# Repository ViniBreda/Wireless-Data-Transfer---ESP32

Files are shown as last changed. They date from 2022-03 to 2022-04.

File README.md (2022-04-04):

# Wireless Data Transfer Between two ESP32 - DOIT Devkit

* File upload via bluetooth available BUT VERY SLOW;
* Send a 500KB file from one ESP32 to another, atleast 100m apart from eachother;
* The PCB of the transmission board was designed considering up to eight I²C devices connected to it to works as a sensor DataLogger;
* The receiver PCB is just a normal DOIT Devkit 1 remake to learn how to use KiCad;
* This is just a concept, not all funcionalities will be developed/tested as the main goal is to send a file over a Wireless Conection.

## TODO : 
 * [x] Enable/Disable BT file transfer
 * [x] Write WiFi AP file transfer
 * [x] RTC sync to log time of [HTTP] GET request
 * [x] RTC sync to execute [HTTP] GET request every 5 minutes
 * [x] Test WiFi Long Range and Normal WiFi
 * [x] Successful test on cellphone hosted WiFi Hotspot - Download file via http://ESP-IP-ADDRESS/download
 * [x] Successful file transfer between two ESP32 boards

## Description:

ESP32 was selected over Arduino boards because:
* it has an internal flash memory that can store more than 500kB of data;
* it has both bluetooth and Wi-Fi onboard;
* it has Wi-Fi Long Range, which is great for file transfers of up to 1Km;
* it's low power mode has very low power consumption, which is great for battery powered projects;
* great market availability, atleast in Brazil;
* higher clock rate;
* internal RTC module;
* cheap price;
* 15 analog pins on DOIT ESP32 DevKit 1 that are great for reading data from sound and light sensors, for example;
* Possibility to code using Arduino syntax, which I'm more familiar to.

Other boards were not considered, such as MSP430 from Texas Instruments or STM32 from STMicroelectronics, because of the difficulties to acquire these boards in Brazil with as many functionalities as ESP32 for as low of a price as a DOIT ESP32 Devkit1.

Both transmissor and receiver schematics can be found below:

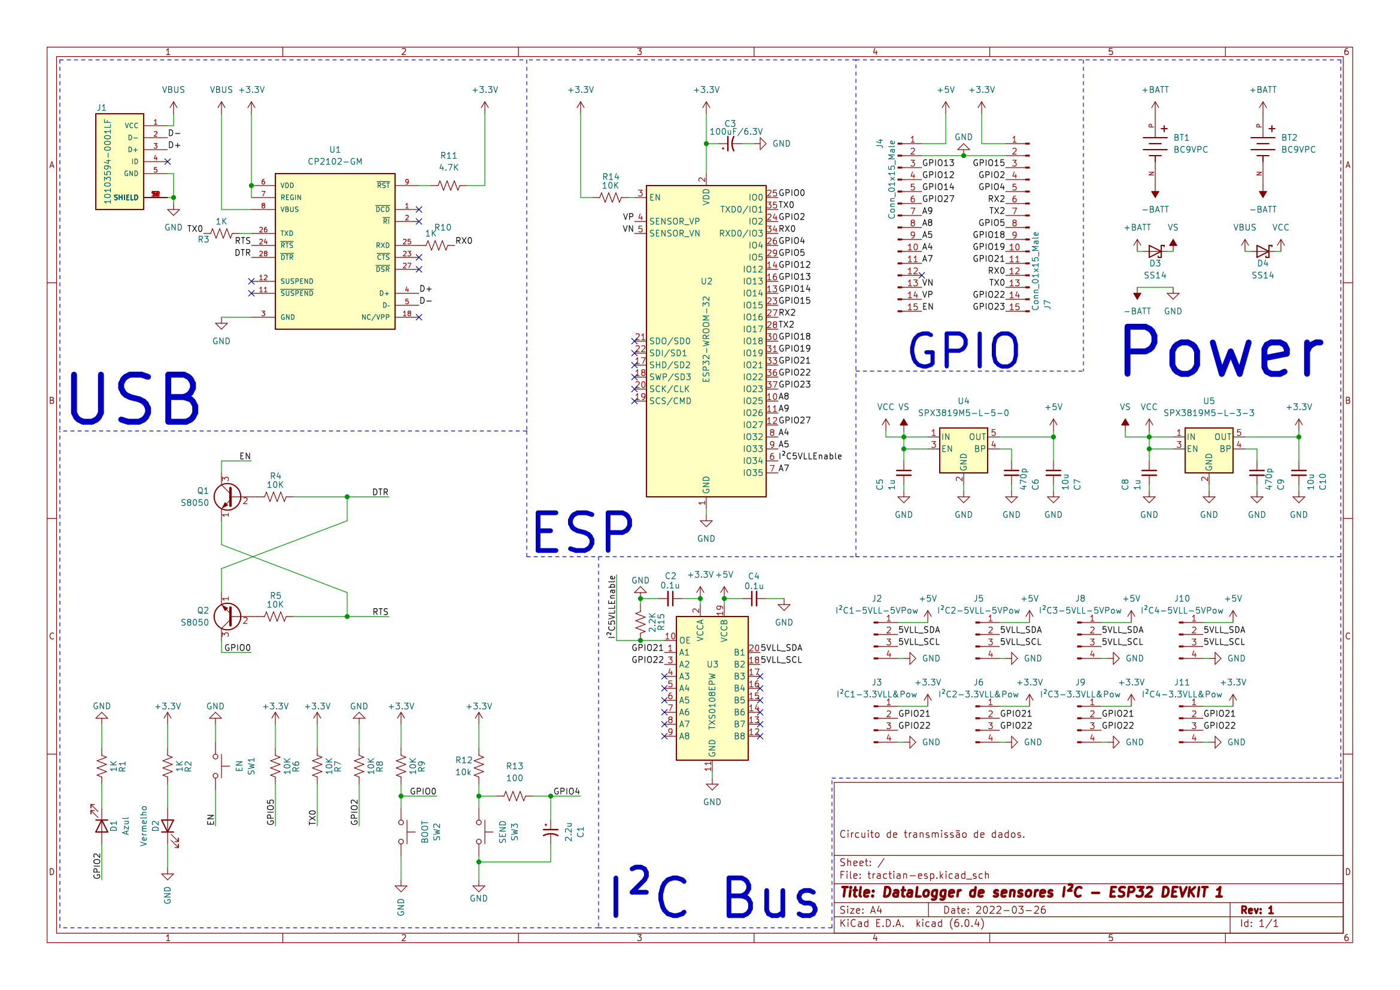
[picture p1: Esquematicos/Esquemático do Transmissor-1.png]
Transmissor


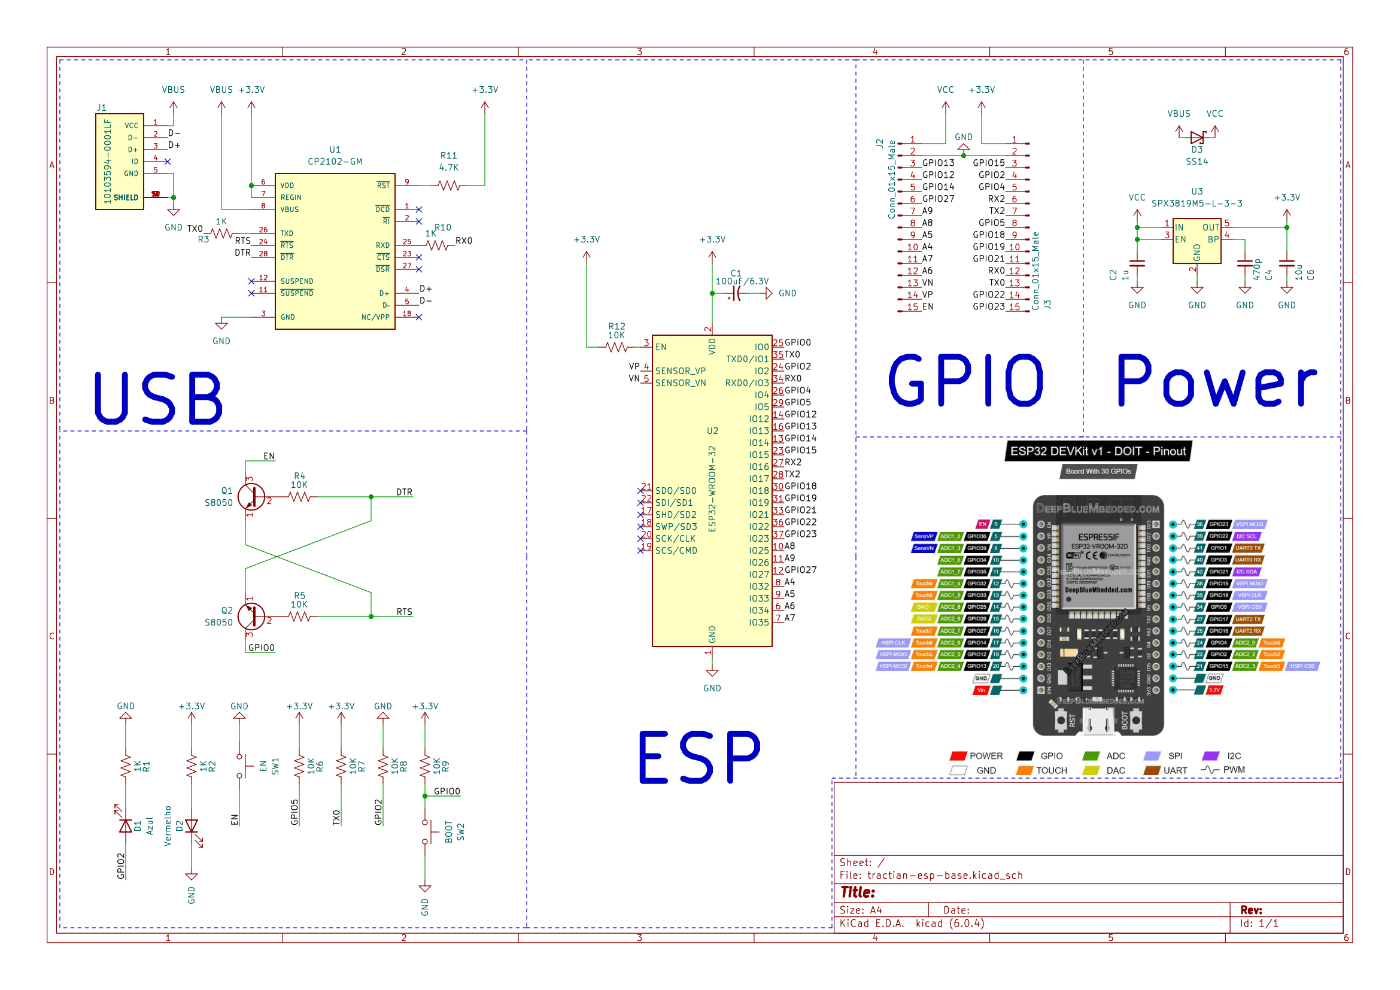
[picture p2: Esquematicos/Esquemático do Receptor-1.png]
Receiver


As there was no need for external components, the schematics would be fairly simple, so I decided to add some details on the transmissor, designing it to be a DataLogger that should read data from it's I²C. This required a logic level converter for I²C devices that need 5V for power and output 5V logic level signals, as ESP32's high level is 3.3V maximum. Also, I used as an example the schematics for the original DOIT ESP32 Devkit 1, changing some of the voltage regulators for ones with lower dropout voltage.

As I was using KiCAD for the first time, designing both the transmissors and receivers was a great challenge and I'm happy with the final result. Common 9V batteries can be used for thisn project and will power the device for many hours.

The transmissor design sacrifices one of the GPIOs with less functionality to have it as I²C enable for the logic level converter. I²C will work normally with this pin on LOW, but I²C for 5V power 5V logic level signal devices this pin has to be put on high while data is being sent and received. It's a great measure to ensure a lower power draw.

The board design for both transmissor and receiver can be found below:

<p align="left">
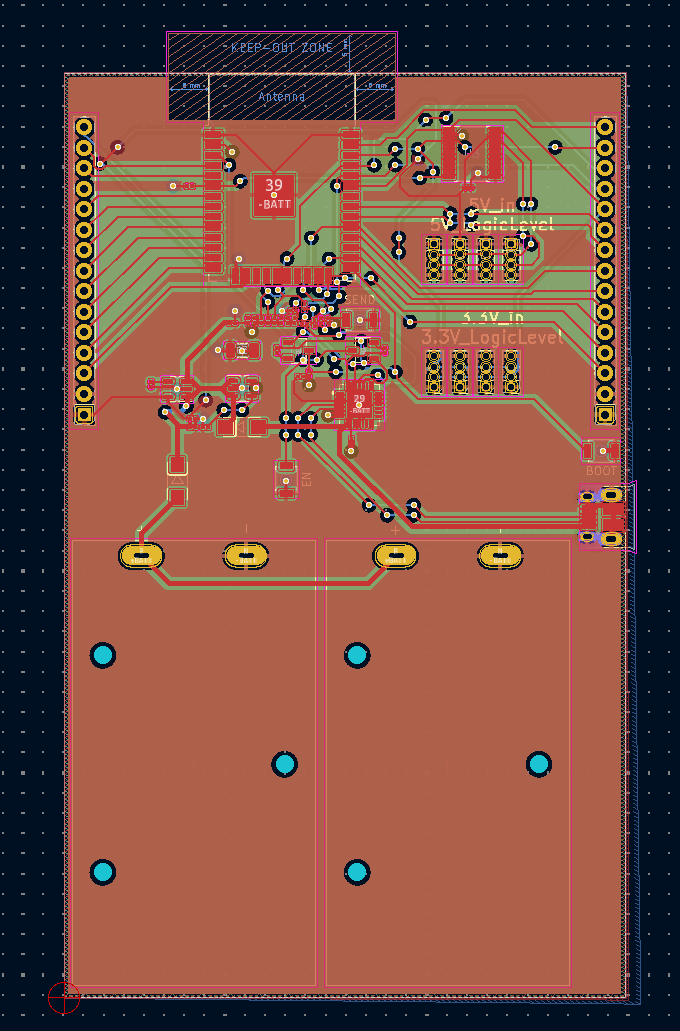
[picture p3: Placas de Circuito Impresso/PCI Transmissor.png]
  
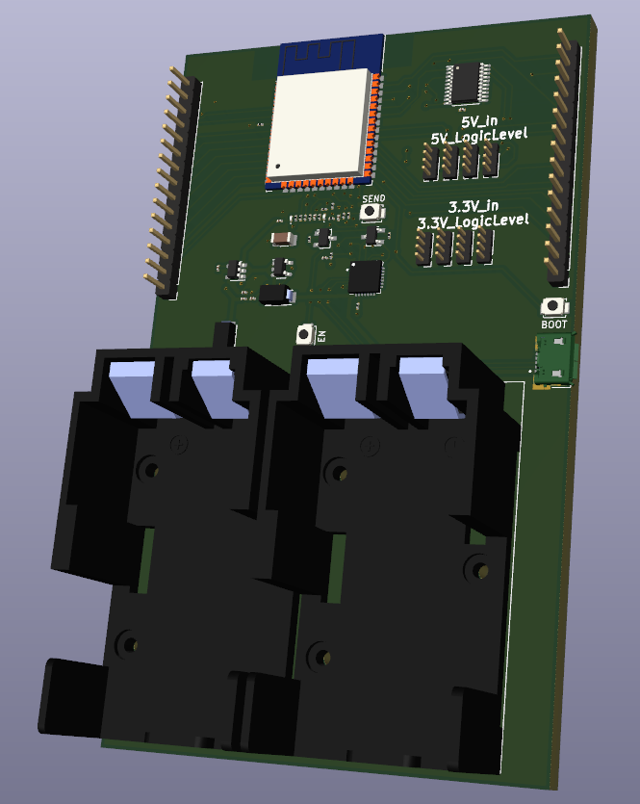
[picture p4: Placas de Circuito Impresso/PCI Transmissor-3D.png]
  
</p>

<p align="left">
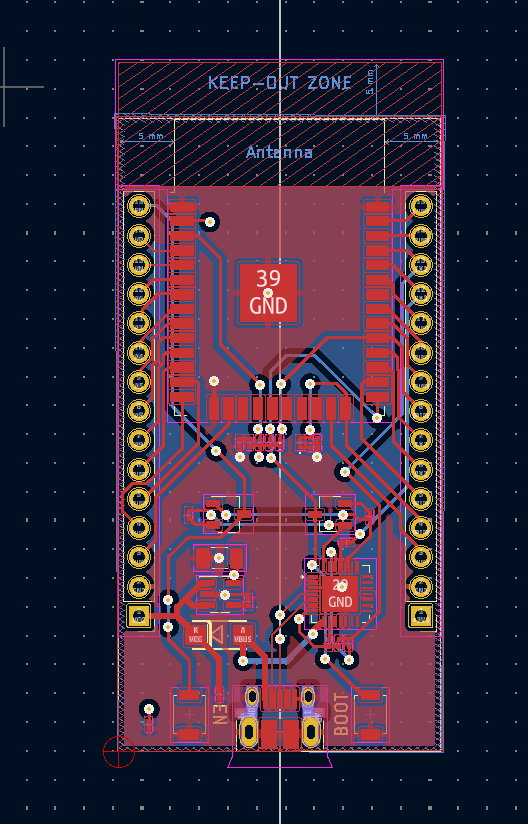
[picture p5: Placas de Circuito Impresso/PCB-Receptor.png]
  
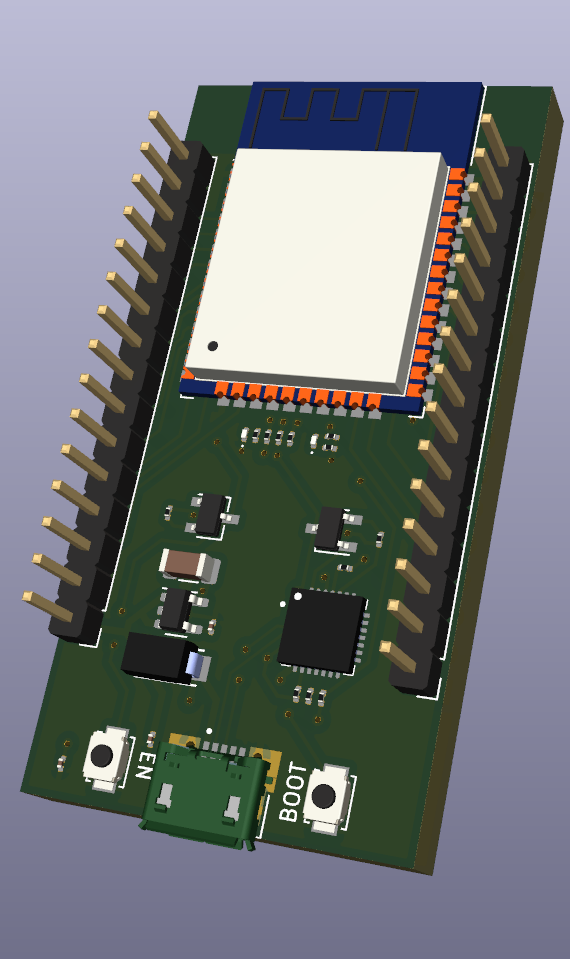
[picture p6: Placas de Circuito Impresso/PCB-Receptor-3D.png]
  
</p>

The code written in this project only simulates the transfer of an existing file stored via bluetooth to folder /storage/loremipsum.txt

But it's easily adaptable to work as it was designed to, as a Data Logger.

* All KiCAD files are stored at **Arquivos KiCAD**;
* All Schematic images are stored at **Esquematicos**;
* All PCB images are stored at **Placas de Circuito Impresso**.

### For more details, read Wireless_Data_Transfer.pdf (in portuguese)

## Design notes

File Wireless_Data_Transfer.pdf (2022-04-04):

# Wireless Data Transfer

### Vinícius Inacio Breda

### 4 de abril de 2022

Resumo

Este documento visa descrever a solução apresentada para o desafio proposto, bem como as justificativas para as tomadas de decisão relevantes para a solução final. Apresentando esquemáticos eletrônicos e design de placa de circuito impresso simples para integração da solução modular. Ao final, tem-se uma solução simples para a transferência de arquivos de, aproximadamente, 500 Kb, entre dois microcontroladores totalmente sem fios, com ao menos 100 metros de separação entre os sistemas e um dos dois sendo alimentado a partir de baterias.

## 1 Introdução

Dispositivos Data Loggers são os responsáveis pela captação e armazenamento de dados de sensores. Estes dados podem ser recolhidos fisicamente ou transmitidos por cabos ou por meio de tecnologias sem fio.
A transferência sem fio de arquivos possui vantagens práticas como, por exemplo, o monitoramento e controle sensoriado de equipamentos em grandes distâncias em locais ou ambientes em que passar cabos é imprático, difícil ou indesejado. O envio dos dados dos sensores ainda é crítico nessas situações, sendo necessária uma solução rápida e simples, facilmente expansível, com componentes relativamente baratos e amplamente disponíveis no mercado.
Os passos do projeto são:
- Definição de Microcontrolador;
- Definição de método de transmissão e recepção de dados;
- Definição de método de armazenamento de dados a serem transmitidos e recebidos;
- Definição da bateria para um dos circuitos;
- Desenvolvimento de esquemático de componentes eletrônico do circuito;
- Desenvolvimento de Placa de Circuito Impresso para ambos os sistemas;
- Desenvolvimento do código do sistema;
- Testes com componentes reais para validação.

| Consumo (mA) | Clock Base | Pinos | | Preço
| Deep Sleep | Máximo | (MHz) | Digitais | PWM | Analógicos | Wi-Fi/BT | (R$)
Arduino UNO Rev.3 | 34 | 410 | 16 | 14 | 6 | 8 | N/N | 50∼90*
* Dependendo da qualidade da placa, SMD ou PTH, original ou paralela

Tabela 1: Características Principais do Arduino

## 2 Microcontrolador

A escolha de microcontroladores é diretamente relacionada à atividade a ser executada. Temos os microcontroladores de empresas como a Texas Instruments ou ST Microelectronics, que são muito capazes de executar as tarefas, porém com uma dificuldade maior de obtenção no mercado brasileiro ao se comparar com placas Arduino ou ESP, mais difundidas no mercado e facilmente encontradas na maioria das lojas de componentes eletrônicos, tanto físicas quanto virtuais.
Levando isto em consideração e, também, o fator familiaridade, pode-se limitar a escolha às placas Arduino e ESP.

### 2.1 Arduino

A comunidade de desenvolvedores de sistemas baseados nos chips Atmel, utilizados nas placas Arduino, é muito ativa e projetos de tudo que se possa imaginar utilizam estes microcontroladores como central de processamento. Pode-se tomar isso como um fator positivo para o Arduino, por ter-se uma grande comunidade de apoio e muitas fontes de informação para desenvolvimento. Existem muitas bibliotecas de apoio para os vários módulos que podem ser utilizados nos projetos, porém, muitas dessas bibliotecas levam em consideração outros microcontroladores. Sendo assim, não se pode tomar isso como ponto para a definição do controlador.
Tem-se então, que recorrer à outros pontos característicos como, por exemplo, recursos presentes na placa base, preço, consumo de energia, etc. Os fatores considerados mais importantes estão apresentados na tabela 2.1. Um ponto importante a se considerar é que as placas Arduino UNO Wi-Fi R2 são consideravelmente mais caras, portanto foram desconsideradas.

### 2.2 ESP

Os microcontroladores da Espressif, mais conhecidos como ESP, também têm se destacado bastante no mundo embarcado, muito por até os modelos mais básicos apresentarem conexão Wi-Fi, podendo ser utilizados mais facilmente para aplicações de internet das coisas (IoT, Internet of Things). Este fator tem um peso grande quando se considera um projeto com transmissão de dados, já que pode-se criar pontos de acesso centrais e conectar diversos microcontroladores neles, que enviam dados periodicamente sem a necessidade da adição de módulos externos extras. Existem ainda, modelos de microcontroladores ESP que possuem bluetooth integrado, o que é mais um ponto positivo para estes modelos.
Dos modelos de ESP a ESP32 é a que melhor se equipara em preço com o Arduino UNO Rev3. Em testes (https://www.instructables.com/ESP32-8266-Wi-Fi-Signal-Strength/) realizados comparando as placas mais comuns encontradas no mercado entre si, tem-se que a ESP32 possui o melhor Wi-Fi, com a ESP-02 sendo

| Consumo (A) | Clock Base | Pinos | | Preço
| Deep Sleep | Máximo | (MHz) | Digitais | PWM | Analógicos | Wi-Fi/BT | (R$)
ESP32 | 5u | 240m | 80∼240 | 36 | 36 | 15 | S/S | 45∼80*
ESP32 DevKit v1 | 5u | 240m | 80∼240 | 25 | 21 | 15 | S/S | 45∼80*

* Dependendo do DevKit e da placa selecionada

Tabela 2: Características Principais da ESP32

a segunda melhor devido a sua antena externa. Para aplicações de DataLogger, a ESP32 apresenta muita flexibilidade por ter um grande número de portas com conversão analógica, possuir uma alta frequência de funcionamento e um baixo consumo de energia, podendo chegar na casa dos micro ampères, como pode ser visto na tabela
2.2. Possui alguns modelos com conector para antena externa, porém, instalar uma antena em um modelo que não possui conector é relativamente simples, basta isolar ambas as saídas para a antena presente na placa, remover sua tinta e soldar um conector SMA.

### 2.3 Definição de Microcontrolador

Para esta aplicação o microcontrolador ESP32 apresenta muitos benefícios que não podem ser ignorados. A presença de Bluetooth e Wi-Fi na mesma placa abrem grandes oportunidades para desenvolvimento e flexibilizam bastante como o projeto pode ser desenvolvido. A possibilidade de se utilizar o Wi-Fi LR para distâncias de até 1 Km em campo aberto, sem a necessidade de módulos ou antenas adicionais torna o controlador ainda mais atrativo. Sendo assim, ja define-se o microcontrolador e a forma de transmissão de dados ao mesmo tempo.
O bluetooth pode ser uma forma de se enviar ao microcontrolador o arquivo que deve ser transmitido pela rede, por exemplo. Há muito o que se explorar com esta solução.
O código será desenvolvido levando em consideração o módulo DOIT ESP32 Dev-Kit1, com 30 pinos.

## 3 Armazenamento

Tendo em vista que um dos objetivos do projeto é o envio de arquivos de 500Kb, é necessária a definição de um local armazená-los. Algumas opções disponíveis são: Um cartão SD, um cartão microSD e a própria memória interna por meio de bibliotecas como a LITTLEFS.
O uso da memória interna é interessante pois não acrescenta custo algum ao projeto, simplificando-o bastante, porém limitando o tamanho dos arquivos que podem ser utilizados. Os módulos SD e microSD são bastante baratos, porém, exigem um cartão adicional, que normalmente não é. Seu uso é recomendado somente caso se deseje armazenar de 4MB até 4GB de dados.

### 3.1 Definição do Armazenamento

Nesta solução a memória interna será utilizada. Caso haja tempo, testes com um módulo microSD serão realizados para comparação de tempo de escrita e leitura.
O armazenamento inicial do arquivo de teste pode ser feito por bluetooth a partir do aplicativo Android Serial Bluetooth Terminal, ou de alguma variante para IOS. Pode-se, também, realizar o upload diretamente pela interface de programação do Arduino ou a partir do PlatformIO.

## 4 Transmissão de Dados

A transmissão de dados foi feita a partir da criação de um servidor e um cliente HTTP. O controlador utilizado como Base de recepção abre um ponto de acesso Wi-Fi para que outros controladores se conectem, este ponto de acesso possui um cliente HTTP que manda GET requests periodicamente a todos os controladores a ele conectados, um a um.
Cada controlador envia o arquivo armazenado em sua memória flash, não volátil, e os dados enviados são anexados ao final do arquivo presente no controlador base. Várias formas de manipular os dados podem ser implementadas, como uma marcação de tempo utilizando o RTC presente na placa. Também pode-se inserir o endereço único MAC de cada controlador para identificar qual enviou o dado. E possível, também, enviar uma ´ linha que possui um identificador a partir do servidor HTTP em cada controlador. No momento em que os controladores são programados, deve-se escolher qual modo de transmissão de dados será utilizado. O Wi-Fi Long Range só é ativado caso seja desejado. Este modo garante transmissões de até 1Km, comprometendo a velocidade de transmissão. Testes de envio em ambos os modos foram feitos e ambos geraram resultados esperados, com o arquivo sendo enviado rapidamente, em questão de segundos.

## 5 Alimentação

A alimentação do sistema não precisa ser muito complexa. Levando em consideração o uso dos modos de baixo consumo de energia do ESP32, uma única bateria seria capaz de mantê-lo ativo por horas. Como a maior parte da energia do sistema será consumida pelo próprio microcontrolador, pode-se levar em conta somente sua corrente máxima de 240mA para o dimensionamento de baterias. O consumo sendo mantido ao máximo por uma hora requer uma bateria de 240mAh, ou seja, para mantê-lo com, aproximadamente, 5 horas de autonomia, 2 baterias de 9V de 600mAh em paralelo seriam suficientes.

## 6 Esquemático

Para efeitos de aprendizado, foi utilizado o esquemático de uma das placas de desenvolvimento da ESP32, que utiliza o chip ESP32-WROOM-32. Algumas modificações foram feitas para adequá-la ao projeto de um DataLogger de sensores I²C, bem como para aumentar a eficiência do envio de energia.

O esquemático dos circuitos se encontram nas figuras 1 e 2. Com uma pequena correção: o botão ”SEND”será utilizado como um chaveador que liga e desliga o bluetooth.

### 6.1 Placa de Circuito Impresso

As placas desenvolvidas para receptor e transmissor estão nas figuras 3 e 4.
Levando em consideração que a ESP32 possui todos os componentes necessários para armazenar um arquivo de 500KB e servir de base para recepção de dados, o circuito torna-se bem simples, sendo quase uma cópia idêntica dos kits de desenvolvimentos, com algumas alterações para eficiência.
Já o circuito de transmissão sofre algumas alterações para que seja possível alimentá-lo com baterias de 9V e manter o pino V in como fonte de alimentação 5V para periféricos ou sensores.
Também foi adicionado um circuito conversor de nível lógico para módulos I²C que possuem saída lógica em 5V, transformando-a em 3.3V, como é suportado pelo ESP32.

## 7 Código

Os códigos estão armazenados no GitHub do projeto, (https://github.com/ViniBreda/Wireless-Data-Transfer---ESP32) utilizado para facilitar o versionamento e controle de alterações do código.

## 8 Testes

Os testes foram realizados em curta distância devido à dificuldade de se realizar testes de longo alcance sem que fossem utilizadas outras formas de alimentação, o que não era possível durante o desenvolvimento. A garantia de distância mínima maior que 100 metros é dada pelo modo de transmissão Wi-Fi Long Range. Porém, pode-se dizer que é possível garantir uma transmissão para mais de 100 metros utilizando o Wi-Fi comum ao se realizar alterações na antena da placa ou utilizar uma placa com conector externo de antenas.
Foi gerado um arquivo chamado ”loremipsum.txt”com pouco mais de 500KB de dados que foi armazenado no sistema interno de um dos controladores, considerado o Transmissor. Este arquivo é enviado por Wi-Fi em poucos segundos.
Não foi utilizada uma forma de medir o tempo de envio, porém isso seria de fácil implementação utilizando as funções de tempo das bibliotecas do Arduino e do ESP32.


6

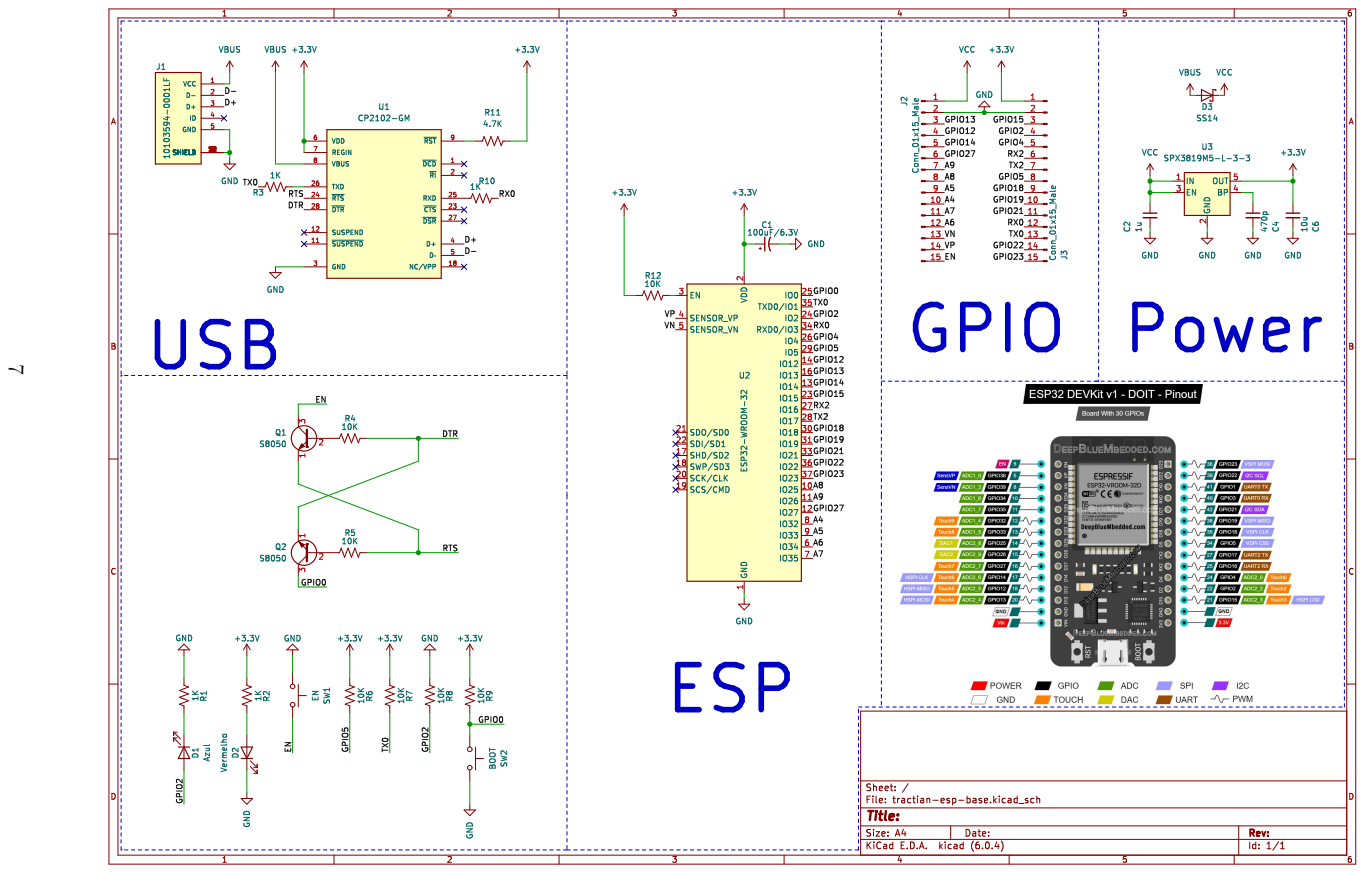
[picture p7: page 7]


Figura 3: PCI - Transmissor


Figura 4: PCI - Receptor


Figura 5: PCI - Transmissor

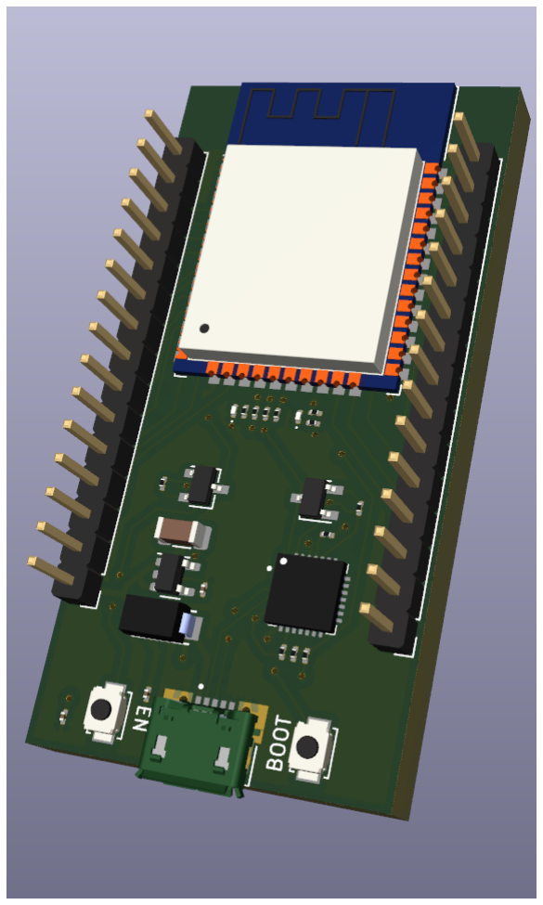
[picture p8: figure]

Figura 6: PCI - Receptor

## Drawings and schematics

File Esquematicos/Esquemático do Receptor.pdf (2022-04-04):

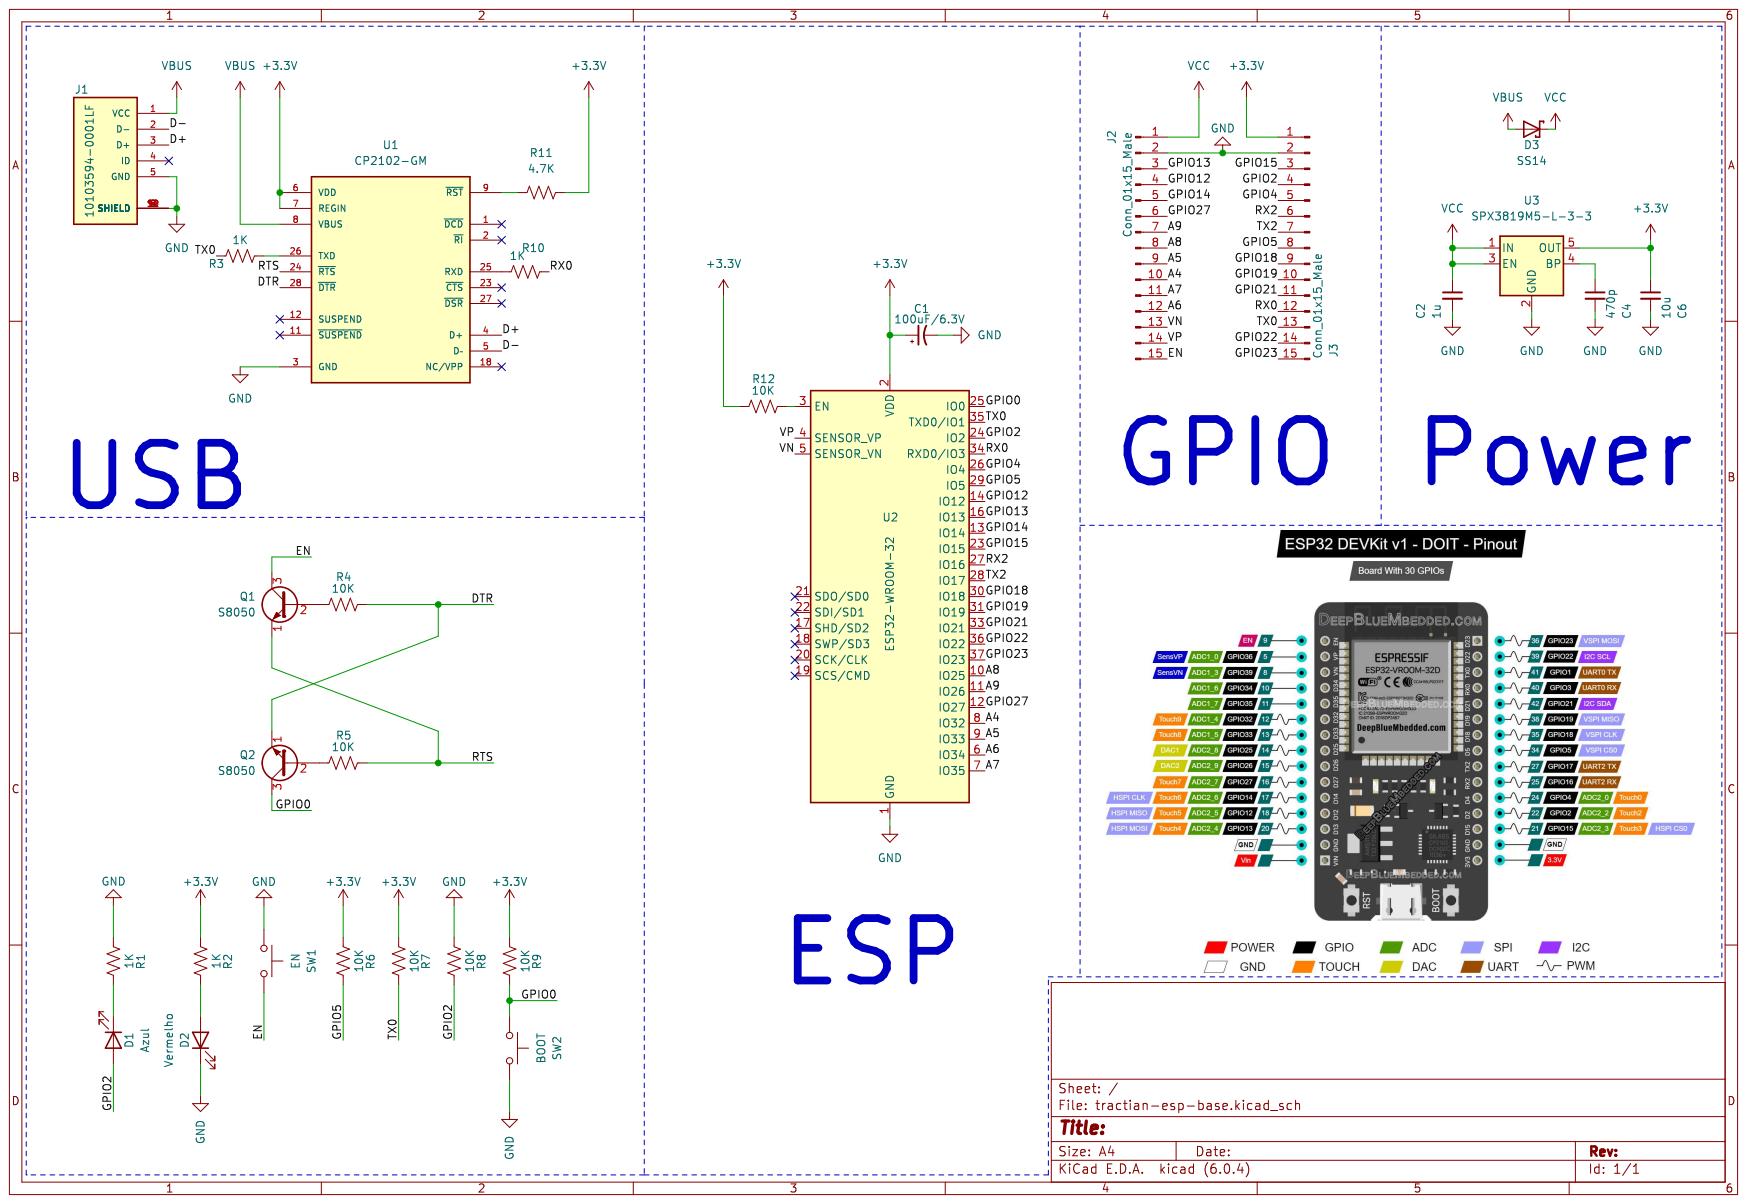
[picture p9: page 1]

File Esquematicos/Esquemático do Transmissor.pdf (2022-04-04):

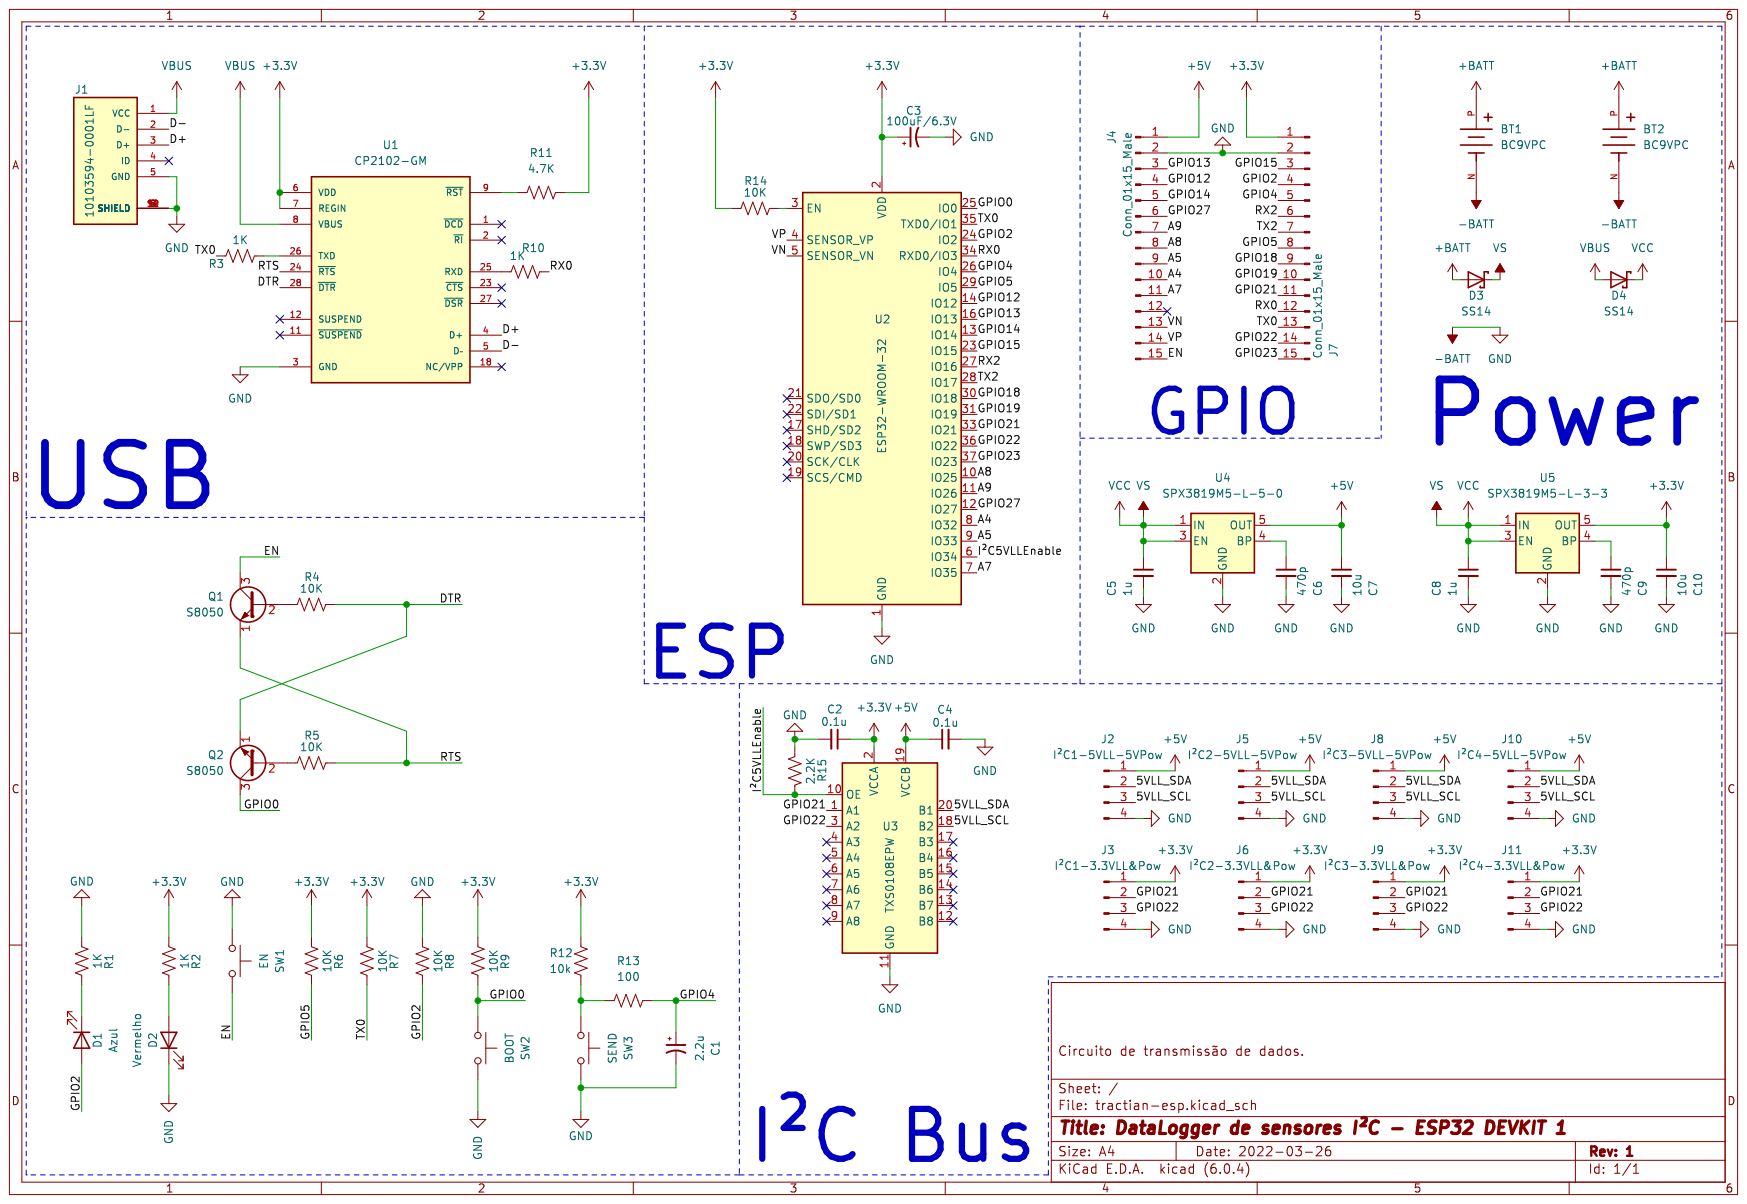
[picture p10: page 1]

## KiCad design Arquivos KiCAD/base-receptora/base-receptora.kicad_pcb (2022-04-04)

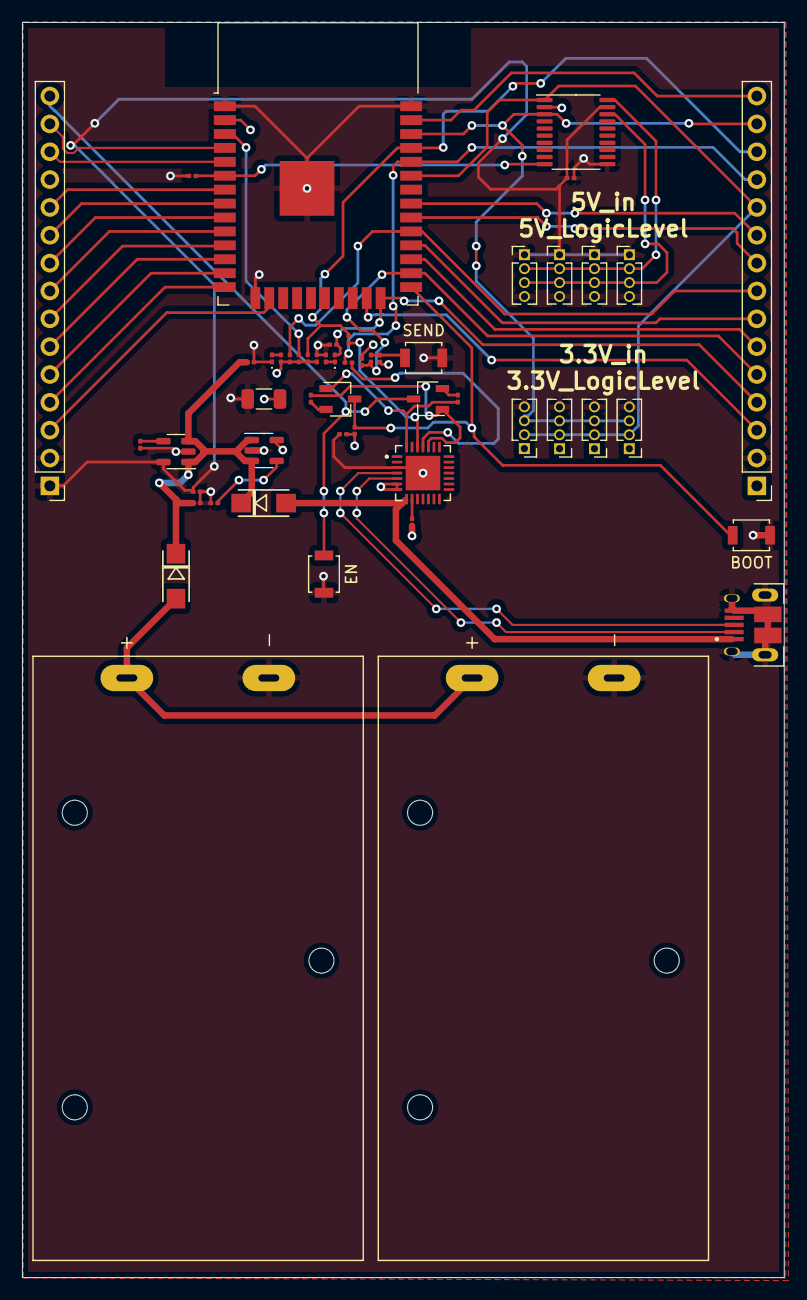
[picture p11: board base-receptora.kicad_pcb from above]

Board: 4 copper layers, 69.5 x 114.5 mm, 52 parts (0 on the bottom side), 50 nets.

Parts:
BT1, BT2: BC9VPC; BAT_BC9VPC
C1: 2.2u; C_0201_0603Metric
C2, C4: 0.1u; C_0201_0603Metric
C3: 100uF/6.3V; C_1206_3216Metric
C5, C8: 1u; C_0201_0603Metric
C6, C9: 470p; C_0201_0603Metric
C7, C10: 10u; C_0201_0603Metric
D1: Azul; LED_0201_0603Metric
D2: Vermelho; LED_0201_0603Metric
D3, D4: SS14; DO-214AC
J1: 10103594-0001LF; AMPHENOL_10103594-0001LF
J2: I²C1-5VLL-5VPow; PinHeader_1x04_P1.27mm_Vertical
J3: I²C1-3.3VLL&Pow; PinHeader_1x04_P1.27mm_Vertical
J4, J7: Conn_01x15_Male; PinHeader_1x15_P2.54mm_Vertical
J5: I²C2-5VLL-5VPow; PinHeader_1x04_P1.27mm_Vertical
J6: I²C2-3.3VLL&Pow; PinHeader_1x04_P1.27mm_Vertical
J8: I²C3-5VLL-5VPow; PinHeader_1x04_P1.27mm_Vertical
J9: I²C3-3.3VLL&Pow; PinHeader_1x04_P1.27mm_Vertical
J10: I²C4-5VLL-5VPow; PinHeader_1x04_P1.27mm_Vertical
J11: I²C4-3.3VLL&Pow; PinHeader_1x04_P1.27mm_Vertical
Q1, Q2: S8050; TSOT-23
R1, R2, R3, R10: 1K; R_0201_0603Metric
R4, R5, R6, R7, R8, R9, R14: 10K; R_0201_0603Metric
R11: 4.7K; R_0201_0603Metric
R12: 10k; R_0201_0603Metric
R13: 100; R_0201_0603Metric
R15: 2.2K; R_0201_0603Metric
SW1: EN; SW_SPST_B3U-1000P
SW2: BOOT; SW_SPST_B3U-1000P
SW3: SEND; SW_SPST_B3U-1000P
U1: CP2102-GM; QFN50P500X500X100-29N
U2: ESP32-WROOM-32
U3: TXS0108EPW; TSSOP-20_4.4x6.5mm_P0.65mm
U4: SPX3819M5-L-5-0; SOT-23-5
U5: SPX3819M5-L-3-3; SOT-23-5

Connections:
+3V3: C2.1, C3.1, C10.1, J3.1, J6.1, J7.1, J9.1, J11.1, R2.1, R6.1, R7.1, R9.1, R11.2, R12.2, R14.1, U1.6 (VDD), U1.7 (REGIN), U2.2 (VDD), U3.2 (VCCA), U5.5 (OUT)
+5V: C4.1, C7.1, J2.1, J4.1, J5.1, J8.1, J10.1, U3.19 (VCCB), U4.5 (OUT)
+BATT: BT1.P, BT2.P, D3.A
-BATT: BT1.N, BT2.N, C1.2, C2.2, C3.2, C4.2, C5.2, C6.2, C7.2, C8.2, C9.2, C10.2, D2.1 (K), J1.5 (GND), J1.6 (SHIELD), J1.7 (SHIELD), J1.8 (SHIELD), J1.9 (SHIELD), J1.10 (SHIELD), J1.11 (SHIELD), J1.S1 (SHIELD), J1.S2 (SHIELD), J2.4, J3.4, J4.2, J5.4, J6.4, J7.2, J8.4, J9.4, J10.4, J11.4, R1.1, R8.1, R15.2, SW1.2, SW2.2, SW3.1, U1.3 (GND), U1.29 (GND), U2.1 (GND), U2.15 (GND), U2.38 (GND), U2.39 (GND), U3.11 (GND), U4.2 (GND), U5.2 (GND)
/5VLL_SCL: J2.3, J5.3, J8.3, J10.3, U3.18 (B2)
/5VLL_SDA: J2.2, J5.2, J8.2, J10.2, U3.20 (B1)
/A4: J4.10, U2.8 (IO32)
/A5: J4.9, U2.9 (IO33)
/A7: J4.11, U2.7 (IO35)
/A8: J4.8, U2.10 (IO25)
/A9: J4.7, U2.11 (IO26)
/D+: J1.3 (D+), U1.4 (D+)
/D-: J1.2 (D-), U1.5 (D–)
/DTR: Q2.1 (E), R4.2, U1.28 (~DTR)
/EN: J4.15, Q1.3 (C), SW1.1
/GPIO0: Q2.3 (C), R9.2, SW2.1, U2.25 (IO0)
/GPIO2: D1.2 (A), J7.4, R8.2, U2.24 (IO2)
/GPIO4: C1.1, J7.5, R13.1, U2.26 (IO4)
/GPIO5: J7.8, R6.2, U2.29 (IO5)
/GPIO12: J4.4, U2.14 (IO12)
/GPIO13: J4.3, U2.16 (IO13)
/GPIO14: J4.5, U2.13 (IO14)
/GPIO15: J7.3, U2.23 (IO15)
/GPIO18: J7.9, U2.30 (IO18)
/GPIO19: J7.10, U2.31 (IO19)
/GPIO21: J3.2, J6.2, J7.11, J9.2, J11.2, U2.33 (IO21), U3.1 (A1)
/GPIO22: J3.3, J6.3, J7.14, J9.3, J11.3, U2.36 (IO22), U3.3 (A2)
/GPIO23: J7.15, U2.37 (IO23)
/GPIO27: J4.6, U2.12 (IO27)
/I²C5VLLEnable: R15.1, U2.6 (IO34), U3.10 (OE)
/RTS: Q1.1 (E), R5.2, U1.24 (~RTS)
/RX0: J7.12, R10.2, U2.34 (RXD0/IO3)
/RX2: J7.6, U2.27 (IO16)
/TX0: J7.13, R3.1, R7.2, U2.35 (TXD0/IO1)
/TX2: J7.7, U2.28 (IO17)
/VN: J4.13, U2.5 (SENSOR_VN)
/VP: J4.14, U2.4 (SENSOR_VP)
unnamed: C6.1, U4.4 (BP)
unnamed: C9.1, U5.4 (BP)
unnamed: D1.1 (K), R1.2
unnamed: D2.2 (A), R2.2
unnamed: Q1.2 (B), R4.1
unnamed: Q2.2 (B), R5.1
unnamed: R3.2, U1.26 (TXD)
unnamed: R10.1, U1.25 (RXD)
unnamed: R11.1, U1.9 (~RST)
unnamed: R12.1, R13.2, SW3.2
unnamed: R14.2, U2.3 (EN)
VBUS: D4.A, J1.1 (VCC), U1.8 (VBUS)
VCC: C5.1, C8.1, D3.K, D4.K, U4.1 (IN), U4.3 (EN), U5.1 (IN), U5.3 (EN)

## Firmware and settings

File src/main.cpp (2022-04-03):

#include <Arduino.h>
#include <WiFi.h>
#include <esp_wifi.h>
#include "LFS_HELPER.hpp"

#define DEVICE 0 // Transmissor -> 0; Base -> 1
#define LONGRANGE 1 // Long Range -> 1; Common Range 0

#define SSID "Data Transmission" // define wifi network name
#define PW   "testpw123" // encrypt pw later

#if DEVICE == 0
  #include <ESPAsyncWebServer.h>
  #include <BluetoothSerial.h>
  #define BTTOGGLE 4 // Bluetooth append to file toggle
  #define BTNAME   "Data Transmissor" // define bluetooth device name
  BluetoothSerial BT; // BluetoothSerial object creation
  const int BUFFER_SIZE = 255;
  char buf[BUFFER_SIZE]; // so Serial RX buffer is not overflown with data
  bool bt_append = false; // whether or not to append received BT data to LoremIpsum.txt
  AsyncWebServer server(80); // Server object creation
  void WiFi_disconnected(WiFiEvent_t event, WiFiEventInfo_t info) {
    Serial.println("Disconnected from WIFI access point");
    Serial.print("WiFi lost connection. Reason: ");
    Serial.println(info.disconnected.reason);
    Serial.println("Reconnecting...");
    WiFi.begin(SSID, PW);
}
#else
  #include <HTTPClient.h>
  #include <time.h>
  #define LED 2 // using board LED to indicate file was received
  struct tm data; // create struct that contains time information
  #define MINUTES 0.1 // define get request time if there are stations connected to the softAP
  time_t tt;
#endif

void setup() {

  #if DEVICE == 0
    pinMode(BTTOGGLE, INPUT);
    delay(50); // delay to give time for input pin to be set properly
  #else
    pinMode(LED, OUTPUT);
    tt = time(NULL); // set current time in seconds for the first time
    timeval tv;
    tv.tv_sec = 1648783914; // set up RTC unix time
    settimeofday(&tv, NULL); // keeps unix time updated
  #endif

  // Setup Serial Monitor
  Serial.begin(115200);

  // Setup File System
  if (!LITTLEFS.begin(true))
    Serial.println("LittleFS not Mounted");
  else
  {
    Serial.println("LittleFS Mounted!");
    createDir(LITTLEFS, "/storage"); // Create directory for file to be stored on first boot
  }

  #if DEVICE == 0
    // WiFi Station Setup
    WiFi.disconnect(true);
    WiFi.mode(WIFI_STA);
    WiFi.begin(SSID, PW);
    while (WiFi.status() != WL_CONNECTED){
      delay(500);
      Serial.println("Connecting to WiFi...");
    }
    Serial.println(WiFi.localIP());
    WiFi.onEvent(WiFi_disconnected, SYSTEM_EVENT_STA_DISCONNECTED);

    #if LONGRANGE == 1
      esp_wifi_set_protocol( WIFI_IF_STA, WIFI_PROTOCOL_LR );
    #endif

    // HTTP Async Server Setup
    server.on("/download", HTTP_GET, [] (AsyncWebServerRequest *request) {
      request->send(LITTLEFS, "/storage/loremipsum.txt", "text/plain", true);
      Serial.println("Sending file: loremipsum.txt");
    });
    server.begin();

  #else // if device is base, creates wifi network
    if (!WiFi.softAP(SSID, PW)) {
      Serial.println("WiFi Access Point not Started.");
    } else { 
      Serial.println("WiFi AP Created!");
      Serial.println(WiFi.softAPIP());
      #if LONGRANGE == 1
        esp_wifi_set_protocol( WIFI_IF_AP, WIFI_PROTOCOL_LR );
      #endif
    }
  #endif
}

void loop() {
  #if DEVICE == 0
    // ==============================   R E A D   B L U E T O O T H   D A T A   ==============================
    if (!digitalRead(BTTOGGLE)) { // debounce circuit output high, command trigger on LOW
      bt_append = !bt_append;     // toggle append enable and disable
      if (bt_append == false)
      {
        BT.end();
        Serial.println("BT Disabled - Append Disabled");
      } else {
        if (!BT.begin(BTNAME)){
          Serial.println("BT Device not Started");
        } else {
          Serial.println("BT Enabled - Append Enabled");
          if (BT.available()) {
            Serial.println("Writing to File loremimpsum.txt...");
            BT.readBytes(buf, BUFFER_SIZE);
            appendFile(LITTLEFS, "/storage/loremipsum.txt", buf);
          }
        }
      } 
    }
  #else    
    if( ( WiFi.softAPgetStationNum() > 0 ) && ( ( tt + (MINUTES * 60) ) <= ( time(NULL) ) )) // if there's something connected and two minutes have passed do get request
    {
      // setup to get connected devices list
      wifi_sta_list_t wifi_sta_list;
      tcpip_adapter_sta_list_t adapter_sta_list;
      memset(&wifi_sta_list, 0, sizeof(wifi_sta_list));
      memset(&adapter_sta_list, 0, sizeof(adapter_sta_list));
      esp_wifi_ap_get_sta_list(&wifi_sta_list);
      tcpip_adapter_get_sta_list(&wifi_sta_list, &adapter_sta_list);
      
      // connected devices by MAC address and IP address
      for (int i = 0; i < adapter_sta_list.num; i++)
      {
        tcpip_adapter_sta_info_t station = adapter_sta_list.sta[i];
        Serial.print("MAC: ");
 
        for(int i = 0; i< 6; i++)
        {
          Serial.printf("%02X", station.mac[i]);  
          if(i<5)Serial.print(":");
        }

        Serial.print("\nIP: ");  
        Serial.println(ip4addr_ntoa(&(station.ip)));
        
        // setup for HTTP request for HTTP Server on the transmission boards
        HTTPClient http;
        http.begin((String)"http://"+ ip4addr_ntoa(&(station.ip)) + ":80/download");
        int httpCode = http.GET();
        if (httpCode > 0)
        {
          Serial.println((String)"[HTTP] GET... code: "+httpCode);

          if(httpCode == HTTP_CODE_OK) 
          {
            File file = LITTLEFS.open("/storage/loremipsum.txt" , FILE_APPEND);
            file.println((String)"IP: " + ip4addr_ntoa(&(station.ip)));
            http.writeToStream(&file);
            file.close();
            //readFile(LITTLEFS, "/storage/loremipsum.txt");
            digitalWrite(LED, HIGH); // turn on OnBoard LED if file was received
          } 
          else
          {
            Serial.println((String)"[HTTP] GET... failed, error: " + http.errorToString(httpCode).c_str());
          }
            
        }
        http.end();
      }
      tt = time(NULL); // updates time variable so it can run again
    }
  #endif
}

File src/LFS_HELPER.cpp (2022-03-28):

#include "LFS_HELPER.hpp"

void listDir(fs::FS &fs, const char * dirname, uint8_t levels){
    Serial.printf("Listing directory: %s\r\n", dirname);

    File root = fs.open(dirname);
    if(!root){
        Serial.println("- failed to open directory");
        return;
    }
    if(!root.isDirectory()){
        Serial.println(" - not a directory");
        return;
    }

    File file = root.openNextFile();
    while(file){
        if(file.isDirectory()){
            Serial.print("  DIR : ");
            Serial.println(file.name());
            if(levels){
                listDir(fs, file.name(), levels -1);
            }
        } else {
            Serial.print("  FILE: ");
            Serial.print(file.name());
            Serial.print("\tSIZE: ");
            Serial.println(file.size());
        }
        file = root.openNextFile();
    }
}

void createDir(fs::FS &fs, const char * path){
    Serial.printf("Creating Dir: %s\n", path);
    if(fs.mkdir(path)){
        Serial.println("Dir created");
    } else {
        Serial.println("mkdir failed");
    }
}

void removeDir(fs::FS &fs, const char * path){
    Serial.printf("Removing Dir: %s\n", path);
    if(fs.rmdir(path)){
        Serial.println("Dir removed");
    } else {
        Serial.println("rmdir failed");
    }
}

void readFile(fs::FS &fs, const char * path){
    Serial.printf("Reading file: %s\r\n", path);

    File file = fs.open(path);
    if(!file || file.isDirectory()){
        Serial.println("- failed to open file for reading");
        return;
    }

    Serial.println("- read from file:");
    while(file.available()){
        Serial.write(file.read());
    }
    file.close();
}

void writeFile(fs::FS &fs, const char * path, const char * message){
    Serial.printf("Writing file: %s\r\n", path);

    File file = fs.open(path, FILE_WRITE);
    if(!file){
        Serial.println("- failed to open file for writing");
        return;
    }
    if(file.print(message)){
        Serial.println("- file written");
    } else {
        Serial.println("- write failed");
    }
    file.close();
}

void appendFile(fs::FS &fs, const char * path, const char * message){
    Serial.printf("Appending to file: %s\r\n", path);

    File file = fs.open(path, FILE_APPEND);
    if(!file){
        Serial.println("- failed to open file for appending");
        return;
    }
    if(file.print(message)){
        Serial.println("- message appended");
    } else {
        Serial.println("- append failed");
    }
    file.close();
}

void renameFile(fs::FS &fs, const char * path1, const char * path2){
    Serial.printf("Renaming file %s to %s\r\n", path1, path2);
    if (fs.rename(path1, path2)) {
        Serial.println("- file renamed");
    } else {
        Serial.println("- rename failed");
    }
}

void deleteFile(fs::FS &fs, const char * path){
    Serial.printf("Deleting file: %s\r\n", path);
    if(fs.remove(path)){
        Serial.println("- file deleted");
    } else {
        Serial.println("- delete failed");
    }
}

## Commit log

2022-03-28 Adição de README e Upload por Bluetooth funcional
2022-03-30 Edit Flash memory size by removing WiFi programming
    [huge_app.csv]
2022-03-31 both devices on the same code + HTPP server and client + soft AP for transmissor
2022-04-01 Proper Partitions Formatting and README update
    [huge_app.csv, partition.csv]
2022-04-01 Properuse of device define and receiver test
2022-04-01 Proper HTTP Communication between boards
2022-04-03 small correction to transmissor code
    [main.cpp]
2022-04-03 Fixed reconnection, testint long range
    [main.cpp]
2022-04-03 fixing BTTOGGLE bug on GPIO2, switching to GPIO4
    [main.cpp]
2022-04-03 Add serial print to get request to know what's happening
2022-04-04 Add project schematics and PCB design
    [base-receptora.kicad_pcb, base-receptora.kicad_sch, receptor.kicad_sch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]
